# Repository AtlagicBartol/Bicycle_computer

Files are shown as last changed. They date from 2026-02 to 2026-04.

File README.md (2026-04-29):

# 🚴 ESP32 Bicycle Computer

Developed a custom bicycle computer system with real-time velocity and distance tracking, including an Android application. 
Designed and implemented embedded firmware in C++ for data acquisition and processing on the hardware device, 
and built an Android app in Kotlin to display, log, and visualize ride statistics. Created custom PCB layouts and s
chematics to support the hardware design and demonstrate full hardware–software integration.

## Features

- Real-time speed measurement  
- Distance tracking  
- Ride time monitoring  
- OLED display interface (SSD1306)
- Android application

## System Overview

- ESP32 – main controller  
- SSD1306 OLED – display
- Hall sensor

## 🛠️ Technologies

- C/C++ (Arduino)
- ESP32
- Kotlin (Android Studio)

## 🚀 Getting Started

### Hardware

- ESP32  
- SSD1306 OLED
- Hall sensor  

### Setup

1. Clone repo
   
git clone https://github.com/AtlagicBartol/Bicycle_computer.git

3. Open in Arduino IDE  

4. Install libraries:
- Adafruit SSD1306  
- Adafruit GFX  

4. Upload to ESP32  

---

## 📄 License

MIT License

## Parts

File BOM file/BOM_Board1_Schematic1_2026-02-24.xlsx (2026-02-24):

No. | Quantity | Comment | Designator | Footprint | Value | Manufacturer Part | Manufacturer | Supplier Part | Supplier
1 | 2 | 0Ω | 0ohm,0ohm | R0805 | 0Ω | 0805W8F0000T5E | UNI-ROYAL(厚声) | C17477 | LCSC
2 | 1 | 1kΩ | 1kohm | R0805 | 1kΩ | 0805W8F1001T5E | UNI-ROYAL(厚声) | C17513 | LCSC
3 | 1 | 4.7uF | 4.7uF | C0805 | 4.7uF | CL21A475KAQNNNE | SAMSUNG(三星) | C1779 | LCSC
4 | 1 | 5.1kΩ | 5.1kohm | R0805 | 5.1kΩ | 0805W8F5101T5E | UNI-ROYAL(厚声) | C27834 | LCSC
5 | 6 | 10kΩ | 10khom,10kohm,10kohm,10kohm,10kohm,10kohm | R0805 | 10kΩ | 0805W8F1002T5E | UNI-ROYAL(厚声) | C17414 | LCSC
6 | 2 | 10uF | 10uF,10uF | C0805 | 10uF | CL21A106KAYNNNE | SAMSUNG(三星) | C15850 | LCSC
7 | 1 | 22Ω | 22ohm | R0805 | 22Ω | 0805W8F220JT5E | UNI-ROYAL(厚声) | C17561 | LCSC
8 | 1 | 22uF | 22uF | C0805 | 22uF | CGA0805X5R226M350MT | HRE(芯声) | C6119901 | LCSC
9 | 1 | 22.1kΩ | 22.1kohm | R0805 | 22.1kΩ | FRC0805F2212TS | FOJAN(富捷) | C2930182 | LCSC
10 | 1 | 47.5kΩ | 47.5kohm | R0805 | 47.5kΩ | FRC0805F4752TS | FOJAN(富捷) | C2999454 | LCSC
11 | 1 | 50Ω | 50ohm | R0805 | 50Ω | ARG05FTC0500 | Viking(光颉) | C2828866 | LCSC
12 | 6 | 100nF | 100nF,100nF,100nF,100nF,100nF,100nF | C0805 | 100nF | C0805B104K500NT | TORCH(火炬) | C476766 | LCSC
13 | 1 | 100Ω | 100ohm | R0805 | 100Ω | FRC0805F1000TS | FOJAN(富捷) | C2907218 | LCSC
14 | 2 | BH-18650-B1BA002 | BT1,BT2 | BATTERY-SMD_18650-1S-L77.1-W20.7-1 |  | BH-18650-B1BA002 | MYOUNG(美阳) | C2988620 | LCSC
15 | 3 | SBD52C05L01 | E1,E2,E3 | SOD-523_L1.2-W0.8-LS1.6-BI |  | SBD52C05L01 | Brightking(君耀电子) | C78433 | LCSC
16 | 1 | PZ254V-11-03P | H1 | HDR-TH_3P-P2.54-V-M |  | PZ254V-11-03P | XFCN(兴飞) | C2937625 | LCSC
17 | 1 | KT-0805G | LED1 | LED0805-R-RD |  | KT-0805G | KENTO | C2297 | LCSC
18 | 2 | SS8050-G(RANGE:120-200) | Q3,Q4 | SOT-23-3_L2.9-W1.3-P1.90-LS2.4-BR |  | SS8050-G(RANGE:120-200) | CJ(江苏长电/长晶) | C164886 | LCSC
19 | 2 | TS-1002S-05026C | SW1,SW2 | KEY-SMD_4P-L6.0-W6.0-P4.50-LS9.0 |  | TS-1002S-05026C | XUNPU(讯普) | C455110 | LCSC
20 | 1 | EC12E2430803 | SW3 | SW-TH_EC12EXXXX |  | EC12E2430803 | ALPSALPINE(阿尔卑斯阿尔派) | C470684 | LCSC
21 | 1 | SK12D07VG4 | Switch1 | SW-TH_SK12D07VG4 |  | SK12D07VG4 | SHOU HAN(首韩) | C393937 | LCSC
22 | 1 | ESP32-WROOM-32E-N8 | U1 | WIFI-SMD_ESP32-WROOM-32E |  | ESP32-WROOM-32E-N8 | ESPRESSIF(乐鑫) | C701342 | LCSC
23 | 1 | CP2102N-A02-GQFN28R | U2 | QFN-28_L5.0-W5.0-P0.50-TL-EP3.3 |  | CP2102N-A02-GQFN28R | SKYWORKS/SILICON LABS(芯科) | C964632 | LCSC
24 | 1 | AMS1117-3.3 | U3 | SOT-223-4_L6.5-W3.5-P2.30-LS7.0-BR |  | AMS1117-3.3 | UMW(友台半导体) | C347222 | LCSC
25 | 1 | HS96L03W2C03 | U4 | OLED-TH_L27.8-W27.2-P2.54_C9900033791 |  | HS96L03W2C03 | HS(汉昇) | C5248080 | LCSC
26 | 1 | HX3144UA | U5 | TO-92S-3_L4.1-W1.7-P1.27-L |  | HX3144UA | HUAXIN(华芯) | C558879 | LCSC
27 | 1 | USB-MICRO XNJ JB | USB3 | MICRO-USB-SMD_HX-USB-MICRO-XNJ-JB |  | USB-MICRO XNJ JB | SHOU HAN(首韩) | C7507410 | LCSC

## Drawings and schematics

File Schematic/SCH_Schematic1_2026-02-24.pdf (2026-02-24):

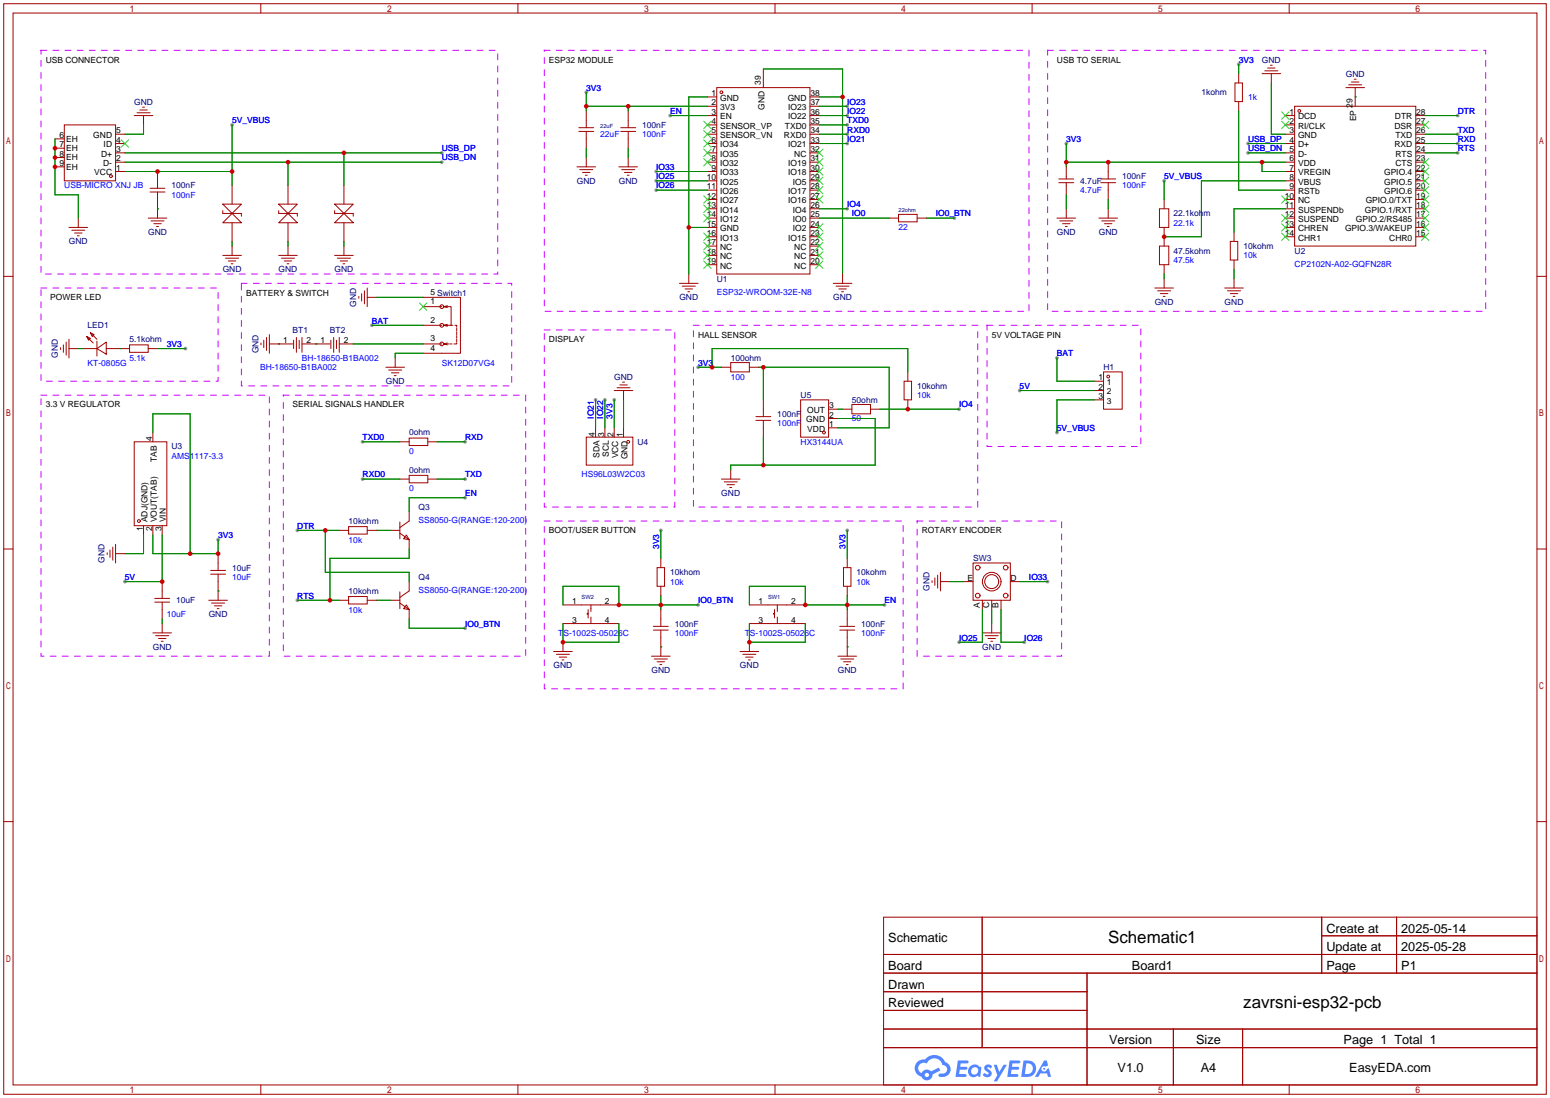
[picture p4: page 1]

Schematic | Schematic1 | Create at | 2025-05-14

Update at | 2025-05-28

Board | Board1 | Page | P1
Drawn | | zavrsni-esp32-pcb
Reviewed

Version | Size | Page 1 Total 1
V1.0 | A4 | EasyEDA.com

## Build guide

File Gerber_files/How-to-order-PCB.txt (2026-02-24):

How to Order PCB

Please refer to:
https://prodocs.easyeda.com/en/pcb/order-order-pcb/index.html

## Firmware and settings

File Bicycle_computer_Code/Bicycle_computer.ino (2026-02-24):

#include <Wire.h>
#include <BfButton.h>
#include <Adafruit_GFX.h>
#include <Adafruit_SSD1306.h>
#include "BluetoothSerial.h"

#define SCREEN_WIDTH 128
#define SCREEN_HEIGHT 64
#define OLED_RESET -1
#define I2C_ADDRESS  0x3C

float tireSize = 0;
bool isDone = true;
float bodyWeight = 0.0;
float startTime;
volatile bool newData = false;
volatile unsigned long interval = 0;
float rpm = 0;
unsigned long lastUpdate = 0;
float calories = 0;
int k = 0;
float MET;
int btnPin = 33;
int DT = 25; //pin b
int CLK = 26; // pin a
int lastStateA;
int counter = 0;
int lastState;
bool buttonPushed = false;
bool buttonHeld = false;
bool buttonPushedTwice = false;
float lastVelocity = -1;
float lastDistance = -1;
float lastCalories = -1;
int lastCounter = -1;
int scrollIndex = 0;
unsigned long lastScrollTime = 0;
const int scrollDelay = 150;

Adafruit_SSD1306 display(SCREEN_WIDTH, SCREEN_HEIGHT, &Wire, OLED_RESET);
BluetoothSerial BTSerial;
BfButton btn(BfButton::STANDALONE_DIGITAL, btnPin, true, LOW);


void setup() {
  Serial.begin(9600);
  BTSerial.begin("ESP32");

  if(!display.begin(SSD1306_SWITCHCAPVCC, I2C_ADDRESS)) {
    while (true);
  }

  display.clearDisplay();
  display.setTextSize(1);
  display.setTextColor(SSD1306_WHITE);

  pinMode(CLK, INPUT_PULLUP);
  pinMode(DT, INPUT_PULLUP);
  pinMode(btnPin, INPUT_PULLUP);

  startTime = millis(); 
  lastState = digitalRead(CLK);

  btn.onPress(&pressHandler)
      .onDoublePress(&pressHandler)
      .onPressFor(&pressHandler, 1000);


  attachInterrupt(digitalPinToInterrupt(4), hallCounter, RISING);
  attachInterrupt(digitalPinToInterrupt(CLK), encodercounter, CHANGE);
}

void loop() {
  btn.read();
  Serial.println(counter);
  unsigned long currentMillis = millis();

  if (BTSerial.hasClient()){
    isConnected();
  }
  else notConnected();
}

void notConnected(){
  if(!tireSize){
      enterTireSizeDisplay();
    }
    else if(!bodyWeight){
      enterBodyWeightDisplay();
    }
    else{
      calculateRPM();
      calories += calculateCalories();
      if(counter < 40){
        displayData();
        delay(1000);
      }
      else settingsDisplay();
    }
}

void isConnected(){
  calculateRPM();
  displayData();
  processBluetoothData();

  static unsigned long lastSendTime = 0;
  unsigned long timer = millis();

  if (!isDone && timer - lastSendTime >= 100) {
      calories += calculateCalories();

      BTSerial.print("R:"); BTSerial.print(rpm);
      BTSerial.print(" K:"); BTSerial.println(k);

      lastSendTime = timer;
  }
}

void hallCounter() {
  unsigned long currentTime = micros(); 
  interval = currentTime - lastUpdate;
  lastUpdate = currentTime;
  newData = true;
  k++;
}

void encodercounter() {
  if (digitalRead(DT) != digitalRead(CLK)) counter++;
  else counter--;
  if (counter < 0) counter = 0;
}

void processBluetoothData() {
    String receivedData = BTSerial.readStringUntil('\n');

    Serial.print("Primljeno: ");
    Serial.println(receivedData);

    if (receivedData.startsWith("T:")) {
        tireSize = receivedData.substring(2).toFloat();
        Serial.print("Veličina gume: ");
        Serial.println(tireSize);
    } else if (receivedData.startsWith("B:")) {
        isDone = (receivedData.charAt(2) == '1');
        Serial.print("isDone: ");
        Serial.println(isDone ? "true" : "false");
        if (!isDone) startTime = millis();
    } else if (receivedData.startsWith("M:")) {
        bodyWeight = receivedData.substring(2).toFloat();
        Serial.print("Tjelesna masa: ");
        Serial.println(bodyWeight);
    } else {
        Serial.print("Nepoznata naredba: ");  
        Serial.println(receivedData); 
    }
}

void calculateRPM(){
  if (newData) {
        noInterrupts();
        unsigned long timeCopy = interval;
        newData = false;
        interrupts();

        if (timeCopy > 0) {
          rpm = 60000000.0 / timeCopy;
          lastUpdate = millis();
        }
    }
  if (millis() - lastUpdate > 2000) rpm = 0;
}

float calculateCalories() {
  float velocity = calculateVelocity();
  MET = (velocity <= 16) ? 4.0 : (velocity <= 19) ? 6.8 : (velocity <= 22) ? 8.0 : (velocity <= 26) ? 10.0 : 12.0;
  return (velocity > 0) ? bodyWeight * MET / 3600.0 : 0;
}

float calculateExtent() {
  return tireSize * 3.14;
}

float calculateDistance() {
  return calculateExtent() * k / 1000.0;
}

float calculateVelocity() {
  return rpm > 0 ? calculateExtent() * rpm / 3.6 : 0.0;
}

void displayData() {
  float velocity = calculateVelocity();
  float distance = calculateDistance();
  float currentCalories = calories;

  display.clearDisplay();

  display.setCursor(0, 0);
  display.print("Brzina(km/h): ");
  display.println(velocity);

  display.setCursor(0, 10);
  display.print("Distanca(km): ");
  display.println(distance);

  display.setCursor(0, 20);
  display.print("Kalorije(kcal): ");
  display.println(currentCalories);

  display.display();  
}

void settingsDisplay(){
  display.clearDisplay();

  display.setCursor(40,0);
  display.print("Postavke");

  display.setCursor(0,10);
  display.print("Velicina gume: ");
  display.println(tireSize);
  display.setCursor(0,20);
  display.print("Pritisni dva puta");

  display.setCursor(0,30);
  display.print("Kilaza: ");
  display.println(bodyWeight);

  display.setCursor(0,40);
  display.print("Drzi dugme");

  if(buttonHeld){
    bodyWeight = 0;
    counter = 0;
    buttonHeld = false;
  }
  if(buttonPushedTwice){
    tireSize = 0;
    counter = 0;
    buttonPushedTwice = false;
  }
  display.display();
}

void enterTireSizeDisplay() {

  display.clearDisplay();

  display.setCursor(0, 0);
  display.print("Velicina gume: "); 
  display.setCursor(0, 10);
  display.println(counter / 100.0);

  if(buttonPushed){tireSize = counter / 100.0; buttonPushed = false; counter = 0;}
  display.display(); 
} 

void enterBodyWeightDisplay() {

  display.clearDisplay();
  display.setCursor(0, 0);
  display.print("Tjelesna tezina: ");
  display.setCursor(0, 10);
  display.println(counter);

  if(buttonPushed){bodyWeight = counter; buttonPushed = false; counter = 0;}
  display.display(); 
}

void pressHandler(BfButton *btn, BfButton::press_pattern_t pattern) {
  switch (pattern) {
    case BfButton::SINGLE_PRESS:
      buttonPushed = true;
      break;

    case BfButton::DOUBLE_PRESS:
      buttonPushedTwice = true;
      break;

    case BfButton::LONG_PRESS:
      buttonHeld = true;
      break;
  }
}

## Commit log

2026-02-24 Adding files
    [BOM_Board1_Schematic1_2026-02-24.xlsx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]
2026-04-29 Add README for ESP32 Bicycle Computer project
    Added detailed project description, features, technologies, and setup instructions for the ESP32 Bicycle Computer.
